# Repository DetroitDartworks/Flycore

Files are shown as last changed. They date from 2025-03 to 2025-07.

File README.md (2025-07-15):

Kodachi Flycore Dart Guides
* Dart Guides should better fit tachi and koda mag feed lips, solving most of the catching and retention issues those mags have with Flycores. Also, edited the screw hole recesses so they can print without supports.

FJZ05 Noidcore
* Noidcore fork designed for the 15mm stroke FJZ05 Solenoid
* Only available in Micro/Mini Wheel flycores due to stroke length
* WIP Beta release. Can be picky about darts and especially dart length

DDW Angled Noidcore
* Noidcore fork combinging the angled Flycore with the Noidcore
* Requires a pusher nub and sits slightly longer than the standard noidcore

DDW Gearcore
* Manual pusher flycore
* Uses a 3:1 rack and pinion gear system
* Straight talon only

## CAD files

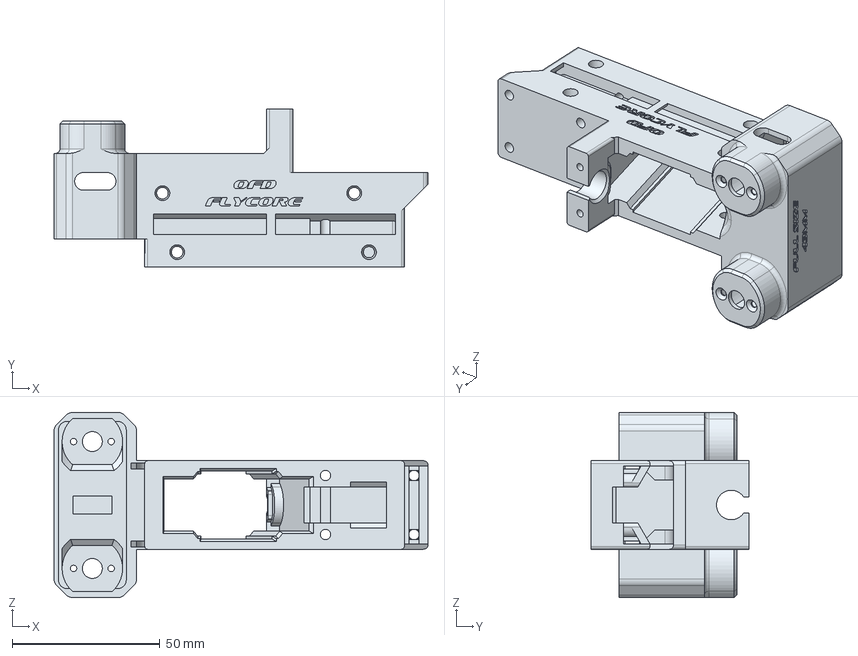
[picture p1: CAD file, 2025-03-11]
DDW Angled Noidcore/STEPs/ATNC - 43mm Full MSB.step
126.8 x 53.5 x 62.7 mm

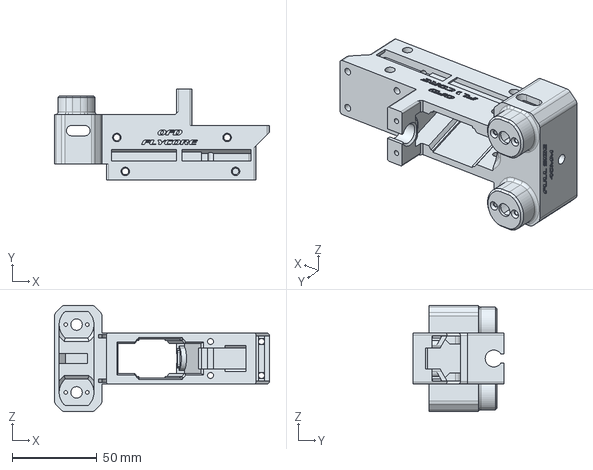
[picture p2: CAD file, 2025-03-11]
DDW Angled Noidcore/STEPs/ATNC - 40mm Full.step
126.8 x 53.5 x 62.7 mm

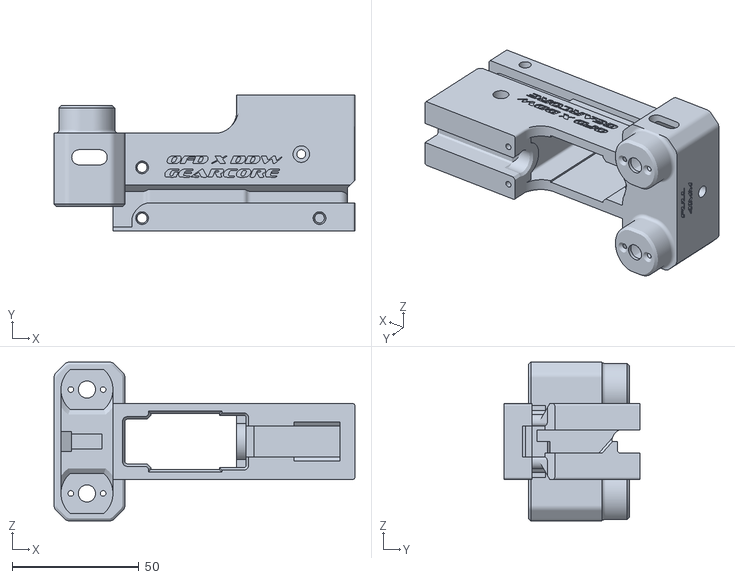
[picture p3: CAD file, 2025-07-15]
Gearcore v1/STLs/Gearcore v1/GearCore v1 - OFD_DDW_GEARCORE_STRAIGHT_FULL_41MM_V1.stl
118.8 x 53.5 x 62.7

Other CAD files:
DDW Angled Noidcore/STEPs/ATNC - 42mm Full.step
DDW Angled Noidcore/STEPs/ATNC - 40mm Full MSB.step
DDW Angled Noidcore/STEPs/ATNC - 41mm Full MSB.step
DDW Angled Noidcore/STEPs/ATNC - 43mm Full.step
DDW Angled Noidcore/STEPs/ATNC - 42mm Full MSB.step
DDW Angled Noidcore/STEPs/ATNC - 41mm Full.step
Gearcore v1/STLs/Gearcore v1/GearCore v1 - OFD_DDW_GEARCORE_STRAIGHT_FULL_43MM_V1.stl
Gearcore v1/STEPs/Gearcore v1/OFD_DDW_GEARCORE_STRAIGHT_FULL_42MM_V1.step
Gearcore v1/STLs/Gearcore v1/GearCore v1 - OFD_DDW_GEARCORE_STRAIGHT_FULL_41.5MM_V1.stl
Gearcore v1/STEPs/Gearcore v1/OFD_DDW_GEARCORE_STRAIGHT_FULL_43MM_V1.step
Gearcore v1/STEPs/Gearcore v1/OFD_DDW_GEARCORE_STRAIGHT_FULL_39.5MM_V1.step
Gearcore v1/STLs/Gearcore v1/GearCore v1 - OFD_DDW_GEARCORE_STRAIGHT_FULL_39.5MM_V1.stl
Gearcore v1/STEPs/Gearcore v1/OFD_DDW_GEARCORE_STRAIGHT_FULL_41MM_V1.step
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

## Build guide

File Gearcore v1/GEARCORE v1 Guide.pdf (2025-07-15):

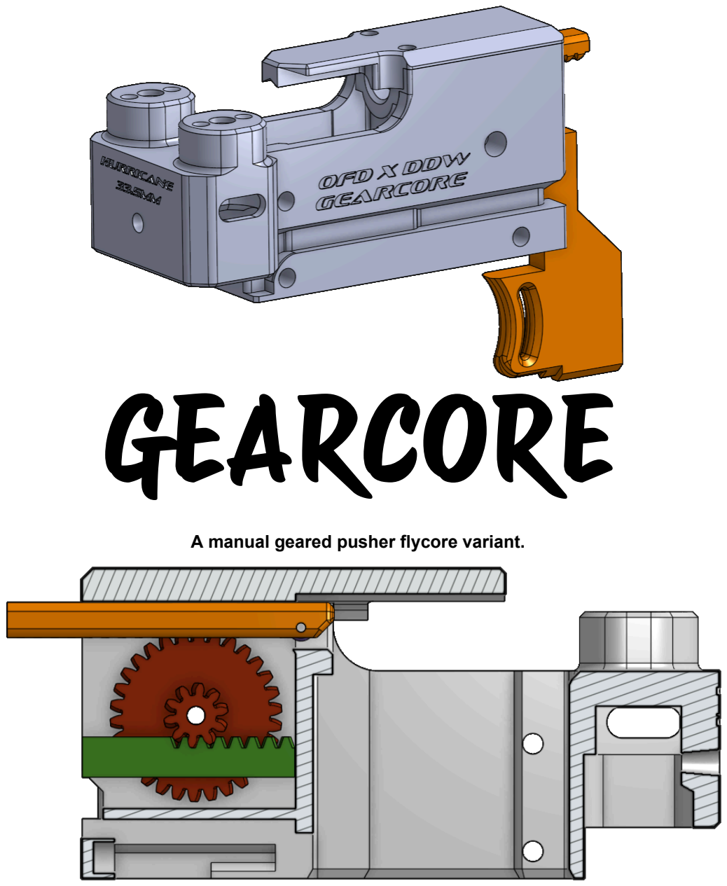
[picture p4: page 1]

# GEARCORE

A manual geared pusher flycore variant.

Required Hardware/Electronics:
8 m3 x 5mmOD x 4-6mmL heat set inserts 7 M3 x 8mm screws
1 m3x20mm screw
2 toy screws (m2.6 x ~10mm)
4 motor screws (m2 x 5mm)
1 mag release spring (I use 5mm x 0.5mm x 25mm)
Step 1: Heat sets
The Gearcore takes 8 heat sets (see below). NOTE: The rear upper heat sets normal to Flycore are removed from Gearcore. There is one spot for a heat set in the upper rear of the right side of the Gearcore; this is for the m3x20mm screw that acts as the axle for the gear.

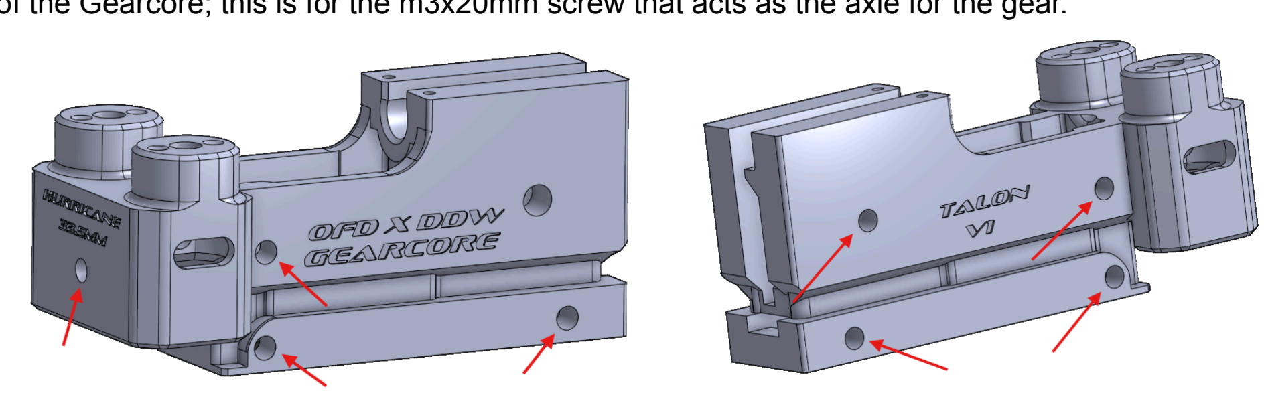
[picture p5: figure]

Step 2: Install the Gear
Insert the gear into the rear of the Gearcore. The smaller side should be to the right side of the core. Align the axle hole of the gear with the hole in the core and secure it with the m3 x 20mm screw. Do not overtighten; the gear should spin freely.
Step 3: Wire the core
Gearcore uses a simple 1 switch circuit (like the typical Stryfe wiring diagram). I recommend running both positive and negative along the same side of the core. Secure the motors with motor screws (m2 x 5mm).
NOTE: Gearcore forgoes the wire channel guides in favor of being able to remove the motors without desoldering. I secure the wires into the channel with a piece of tape.

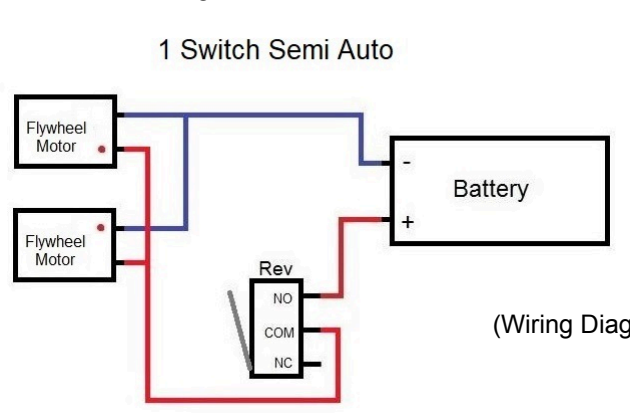
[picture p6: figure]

(Wiring Diagram courtesy of Captain Xavier)

Step 3: Install Flywheels & Mag Release
Use whichever flywheels and whichever mag release fit your build.
Step 4: Prep Pusher
Insert the roller into the slot in the Pusher and use a bit of 1.75mm filament as a pin. Cut the filament flush with the pusher arm.
Step 5: Insert Trigger
This step may vary from blaster to blaster, but the trigger needs to be fully inserted into the core before the pusher can be installed. The trigger rack inserts to the right of the big gear, underneath the smaller section of gear.
Note: On the Bahamut, the trigger is installed in the blaster first and then the core is slid into position so that the trigger rack inserts itself.
Step 6: Install Pusher & Dart Guide
Once the trigger has been inserted, the easiest way to install the pusher is to drop it into place from the top and then secure the pusher guide on top of it with the 2 toy screws.
The Pusher can also be fed in through the front after the pusher guide is installed, but this is a trial and error process to align the gears and racks properly.
Step 7: Continue Blaster Assembly
Step 8: ???
Step 9: Profit

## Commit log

2024-03-11 Add files via upload
    WIP FJZ05 Solenoid Flycore
    -Solenoid Flycore for use with the 15mm stroke FJZ05 Solenoid.
    -Can be picky about darts and dart lengths. Only available in FTW/Hurricane sized cores due to pusher stroke length. This is a WIP Beta release.
    [FJZ05 Solenoid Flycore - FTW 22.5mm.stl, FJZ05 Solenoid Flycore - FTW 22mm.stl, FJZ05 Solenoid Flycore - FTW 23mm.stl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]
2025-07-15 Add files via upload
    Gearcore - Manual pusher Flycore
